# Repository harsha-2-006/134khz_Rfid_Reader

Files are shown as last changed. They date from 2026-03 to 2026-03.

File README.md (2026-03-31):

# 134.2 kHz RFID Reader (EM4095 + ESP32)

> Designed and built as a hands-on hardware project to understand low-frequency RFID systems.

---

## 🔧 Features
- Operates at 134.2 kHz (LF RFID)
- Custom-designed PCB with integrated coil antenna
- EM4095 RFID analog front-end
- ESP32 for data processing and communication

---

## 🧠 Working Principle
The coil antenna generates a magnetic field at 134.2 kHz.  
When an RFID tag enters the field, it modulates the signal.  
This modulated signal is detected and demodulated by the EM4095.  
The ESP32 reads and processes the decoded data.

---

## 📷 Project Images

### PCB Layout
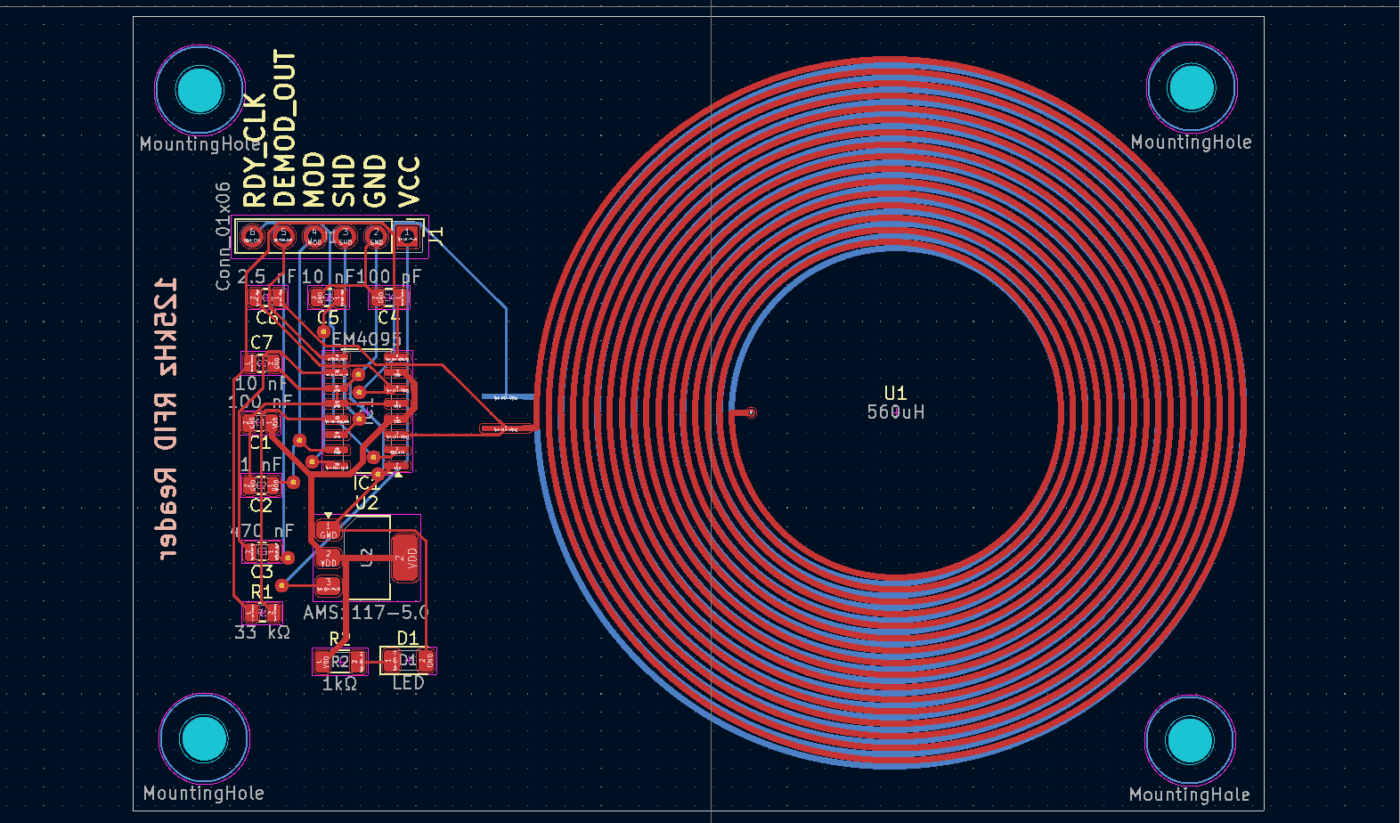
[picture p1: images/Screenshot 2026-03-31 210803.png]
PCB


### 3D View
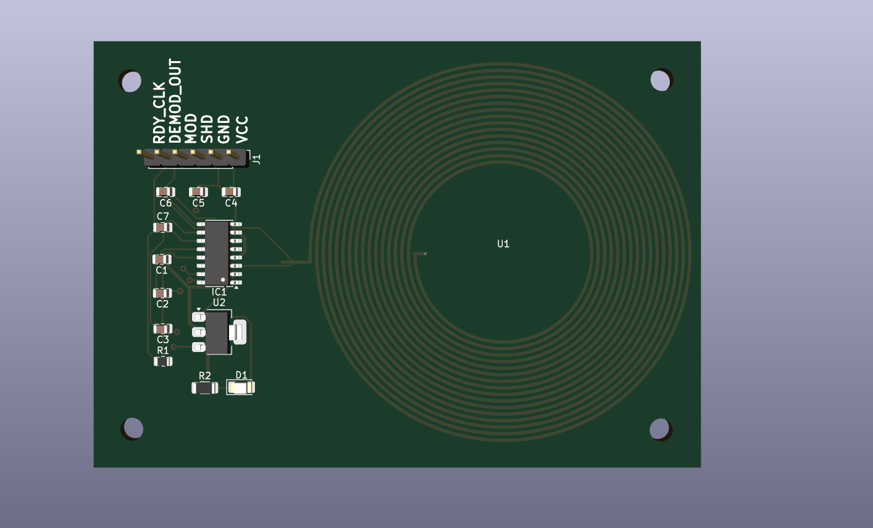
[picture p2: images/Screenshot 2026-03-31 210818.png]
3D


### Schematic
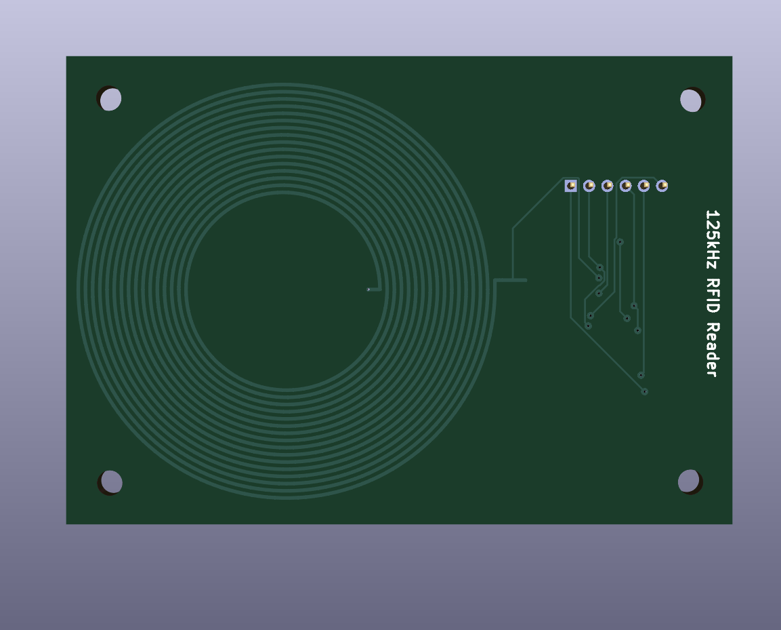
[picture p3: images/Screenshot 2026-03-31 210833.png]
Schematic


---

## 🛠️ Hardware Used
- EM4095 RFID IC  
- ESP32  
- Custom PCB coil antenna  

---

## 📂 Project Structure

- `hardware/` → PCB design and schematic files  
- `software/` → ESP32 code  
- `images/` → project images  

---

## 📁 Files Included
- PCB layout files  
- Schematic design  
- ESP32 firmware  

---

## ⚠️ Improvements / Future Work
- Improve coil tuning for better resonance  
- Enhance signal filtering for stability  
- Increase read range and reliability  

---

## 🚀 Applications
- Animal tracking systems  
- Access control  
- Identification systems  

---

## 📌 Status
Project completed and tested.

---

## 🤝 Contributions
This is a personal learning project. Suggestions and improvements are welcome.

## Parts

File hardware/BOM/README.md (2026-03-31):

# 134.2 kHz RFID Reader (EM4095 + ESP32)

> Designed and built as a hands-on hardware project to understand low-frequency RFID systems.

---

## 🔧 Features
- Operates at 134.2 kHz (LF RFID)
- Custom-designed PCB with integrated coil antenna
- EM4095 RFID analog front-end
- ESP32 for data processing and communication

---

## 🧠 Working Principle
The coil antenna generates a magnetic field at 134.2 kHz.  
When an RFID tag enters the field, it modulates the signal.  
This modulated signal is detected and demodulated by the EM4095.  
The ESP32 reads and processes the decoded data.

---

## 📷 Project Images

### PCB Layout
PCB

### 3D View
3D

### Schematic
Schematic

---

## 🛠️ Hardware Used
- EM4095 RFID IC  
- ESP32  
- Custom PCB coil antenna  

---

## 📂 Project Structure

- `hardware/` → PCB design, antenna, and hardware-related files  
- `software/` → ESP32 code  
- `images/` → project visuals  

---

## 📦 Hardware Details

- `antenna_134.2kHz/` → Coil antenna design files  
- `pcb_coils/` → Coil design variations and experiments  
- `EM4095/` → Reference circuits and IC-related files  

---

## 📋 Bill of Materials (BOM)

The complete list of components used in this project is available here:

`hardware/BOM/rfid_reader_bom.csv`

### Key Components
- EM4095 RFID IC  
- ESP32  
- Capacitors (100nF, tuning capacitors)  
- Resistors  
- Coil antenna  

---

## ▶️ How to Use

1. Open hardware files using KiCad  
2. Upload ESP32 code using Arduino IDE  
3. Power the circuit and monitor output via serial  

---

## ⚠️ Improvements / Future Work
- Improve coil tuning for better resonance  
- Enhance signal filtering for stability  
- Increase read range and reliability  

---

## 🚀 Applications
- Animal tracking systems  
- Access control  
- Identification systems  

---

## 📌 Status
Project completed and tested.

---

## 🤝 Contributions
This is a personal learning project. Suggestions and improvements are welcome.

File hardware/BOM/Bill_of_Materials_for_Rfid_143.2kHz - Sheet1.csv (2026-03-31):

Name | Reference | Qty | Value | Footprint | Datasheet | Buying Links
SMD Capacitor | C1 | 1 | 100 nF | Capacitor_SMD:C_0805_2012Metric | 885012207080 Datasheet WCAP-CSGP Ceramic Capacitors 0805 | Online in Robu.in , Buy 100nF 50V Ceramic Capacitor (MLCC) - SMD 0805 - KTRON India , https://www.sunrom.com/p/100nf-104-0805-2012-metric-50v-x7r-mlcc
SMD Capacitor | C2 | 1 | 1 nF | Capacitor_SMD:C_0805_2012Metric | 885012207080 Datasheet WCAP-CSGP Ceramic Capacitors 0805 | 1nF 102 0805 (2012 metric) 50V X7R MLCC SMD [4035] : Sunrom Electronics
SMD Capacitor | C3 | 1 | 470 nF | Capacitor_SMD:C_0805_2012Metric | 885012207080 Datasheet WCAP-CSGP Ceramic Capacitors 0805 | 470nF 474 0805 (2012 metric) 50V X7R MLCC SMD [3944] : Sunrom Electronics
SMD Capacitor | C4 | 1 | 100 pF | Capacitor_SMD:C_0805_2012Metric | 885012207080 Datasheet WCAP-CSGP Ceramic Capacitors 0805 | 100pF 101 0805 (2012 metric) 50V X7R MLCC SMD [4479] : Sunrom Electronics
SMD Capacitor | C5,C7 | 2 | 10 nF | Capacitor_SMD:C_0805_2012Metric | 885012207080 Datasheet WCAP-CSGP Ceramic Capacitors 0805 | 10nF 103 0805 (2012 metric) 50V X7R MLCC SMD [4034] : Sunrom Electronics
SMD Capacitor | C6 | 1 | 2.5 nF | Capacitor_SMD:C_0805_2012Metric | 885012207080 Datasheet WCAP-CSGP Ceramic Capacitors 0805 | 08055C242KAT2A KYOCERA AVX | Mouser India
SMD LED | D1 | 1 | LED | LED_SMD:LED_1206_3216Metric | Microsoft Word - 170_SLOAN_01C_03.12_SMD1206.doc | Buy 1206 Surface mount LED White Online at Best Price | Robu.in
IC | IC1 | 1 | EM4095 | Package_SO:SOIC-16_3.9x9.9mm_P1.27mm | 4095 Data Sheet | EM4095HMSO16B+ EM Microelectronic | RF and Wireless | DigiKey https://inkocean.in/products/em4095-em4095hms016a-sop16-emc
6 Pin Connector | J1 | 1 | Conn_01x06 | Connector_PinHeader_2.54mm:PinHeader_1x06_P2.54mm_Vertical | ~ | Buy Header Pins 40x1 - 2.54mm Pitch - Brass - KTRON India
SMD Resistor | R1 | 1 | 33 kΩ | Resistor_SMD:R_0805_2012Metric | 0805 datasheet(1/6 Pages) MACOM | SMD High Power Precision Resistors | 33K 1% 0805 [4321] : Sunrom Electronics
SMD Resistor | R2 | 1 | 1kΩ | Resistor_SMD:R_1206_3216Metric | https://www.vishay.com/docs/20035/dcrcwe3.pdf | Buy RT1206FRE071KL Resistors Online in India | Robu.in
Voltage Regulator | U2 | 1 | AMS1117-5.0 | Package_TO_SOT_SMD:SOT-223-3_TabPin2 | AMS1117-3.3 | https://www.sunrom.com/p/1117-5v-1a-sot223-low-drop-linear-voltage-regulator?utm_source=chatgpt.com https://kitsguru.com/products/ams1117-5v-voltage-regulator-ic-smd-sot-223-package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 https://www.fabtolab.com/ams1117-5-cost-effective-low-dropout-ldo-voltage-regulator-current-1-amp-maximum-input-15v https://robu.in/product/ams1117-5-0v-1a-sot-223-voltage-regulator-ic-pack-of-5-ics/

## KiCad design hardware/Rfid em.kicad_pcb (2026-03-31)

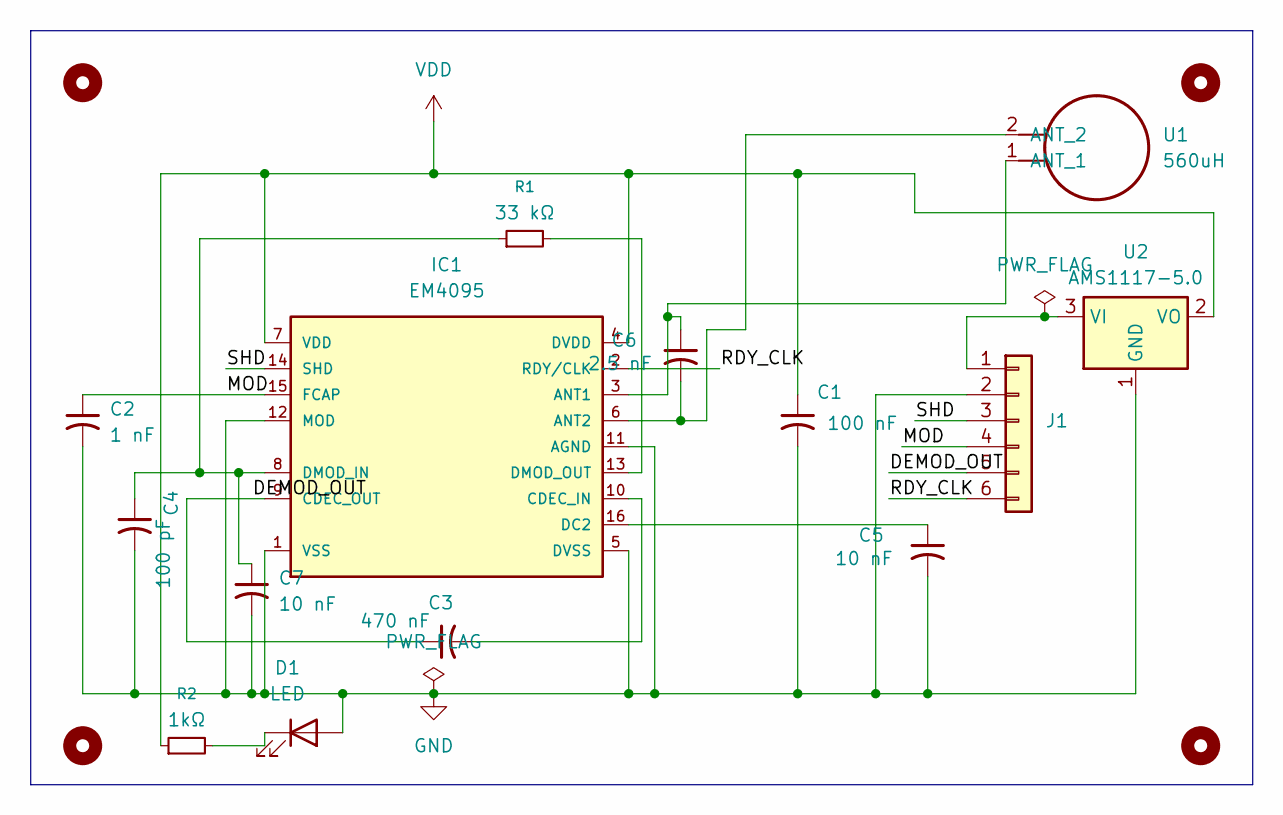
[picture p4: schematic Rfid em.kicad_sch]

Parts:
C1: 100 nF; C_0805_2012Metric
C2: 1 nF; C_0805_2012Metric
C3: 470 nF; C_0805_2012Metric
C4: 100 pF; C_0805_2012Metric
C5, C7: 10 nF; C_0805_2012Metric
C6: 2.5 nF; C_0805_2012Metric
D1: LED; LED_1206_3216Metric
H1, H2, H3, H4: MountingHole; MountingHole_3.5mm
IC1: EM4095; SOIC-16_3.9x9.9mm_P1.27mm
J1: Conn_01x06; PinHeader_1x06_P2.54mm_Vertical
R1: 33 kΩ; R_0805_2012Metric
R2: 1kΩ; R_1206_3216Metric
U1: 560uH; RFID_COIL
U2: AMS1117-5.0; SOT-223-3_TabPin2

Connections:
/DEMOD_OUT: C3.1, IC1.9 (CDEC_OUT), J1.5
/MOD: C2.1, IC1.15 (FCAP), J1.4
/RDY_CLK: IC1.2 (RDY/CLK), J1.6
/SHD: IC1.14 (SHD), J1.3
GND: C1.2, C2.2, C4.2, C5.2, C7.2, D1.2 (A), IC1.1 (VSS), IC1.5 (DVSS), IC1.11 (AGND), IC1.12 (MOD), J1.2, U2.1 (GND)
unnamed: D1.1 (K), R2.2
unnamed: C6.1, IC1.3 (ANT1), U1.1 (ANT)
unnamed: C6.2, IC1.6 (ANT2), U1.2 (ANT)
unnamed: C3.2, IC1.10 (CDEC_IN)
unnamed: C5.1, IC1.16 (DC2)
unnamed: C4.1, C7.1, IC1.8 (DMOD_IN), R1.1
unnamed: IC1.13 (DMOD_OUT), R1.2
unnamed: J1.1, U2.3 (VI)
VDD: C1.1, IC1.4 (DVDD), IC1.7 (VDD), R2.1, U2.2 (VO)

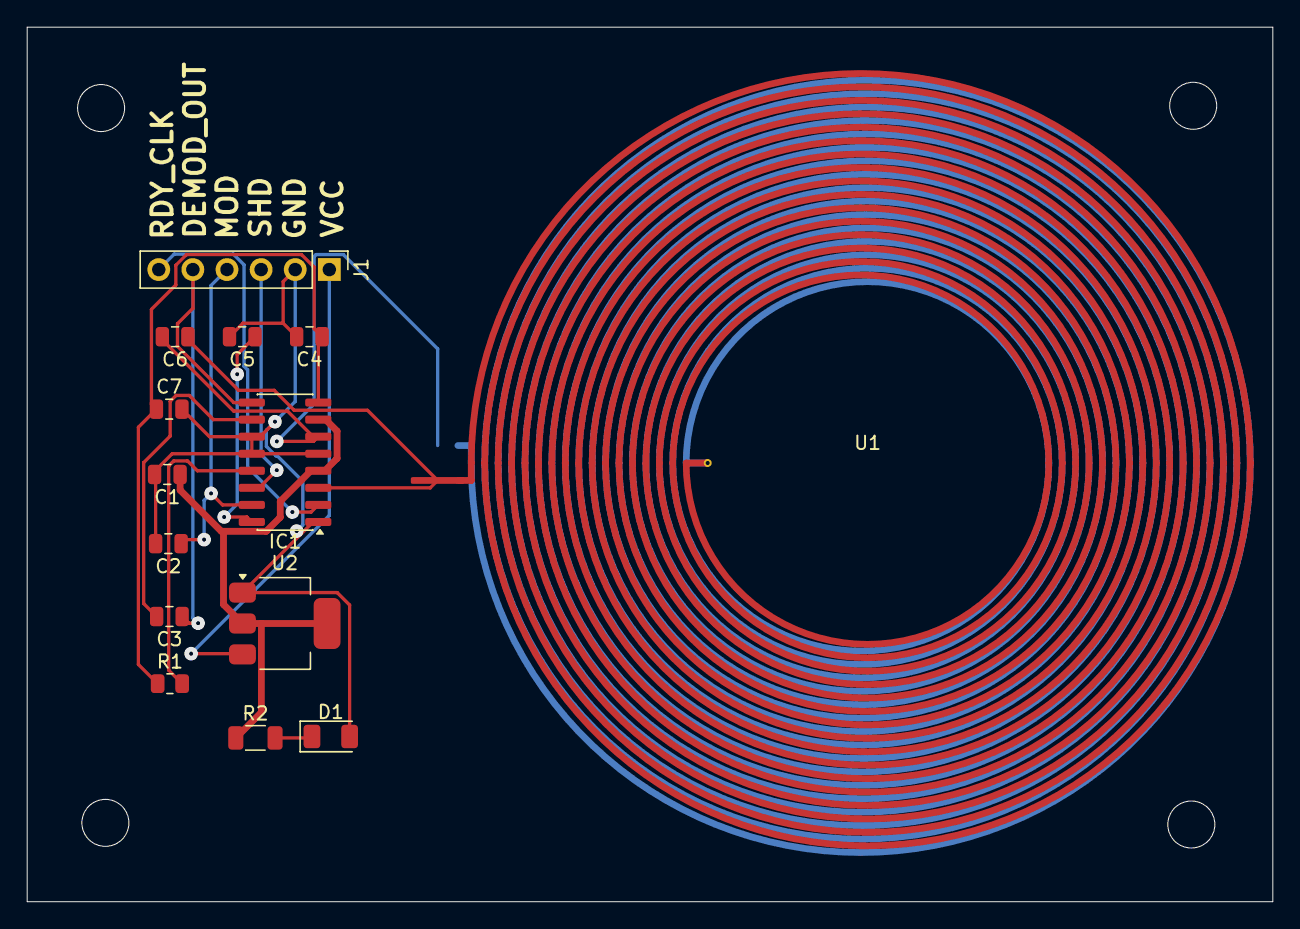
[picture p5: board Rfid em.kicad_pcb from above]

Board: 2 copper layers, 92.7 x 65.1 mm, 18 parts (0 on the bottom side), 14 nets.
